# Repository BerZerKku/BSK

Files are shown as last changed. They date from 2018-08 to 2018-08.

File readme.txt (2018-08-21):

Плата BSK.
Сделана в OrCAD 16.6-2015-S073.

BSK_02v4

Код ПП: 3.140.786
Код ПП в сборе (1-16 команды): 2.141.036

Предназначена для работы в любом командном аппарате АВАНТ.

Изенения:

Ширина контактных площадки TQFP уменьшена на 0.05мм.
Добавлены супрессоры в цепях +24VE, +3.3V
Добавлены тестовые колодки и светодиоды

***Стэк:
35мкм  TOP
0.36мм e=4.5
35мкм  IN1_GND
0.71мм e=4.5
35мкм  IN2_PWR
0.36мм e=4.5
35мкм  BOTTOM

Материал: FR4 High Tg (e=4.1, plating thickness=25um))
Финишное покрытие контактных площадок: HAL
Паяльная маска: зеленая.
Вырезы на плате нет.
Отверстия указаны после металлизации.
***Технологическое поле не менее 5мм по всем сторонам, скрайбированием.

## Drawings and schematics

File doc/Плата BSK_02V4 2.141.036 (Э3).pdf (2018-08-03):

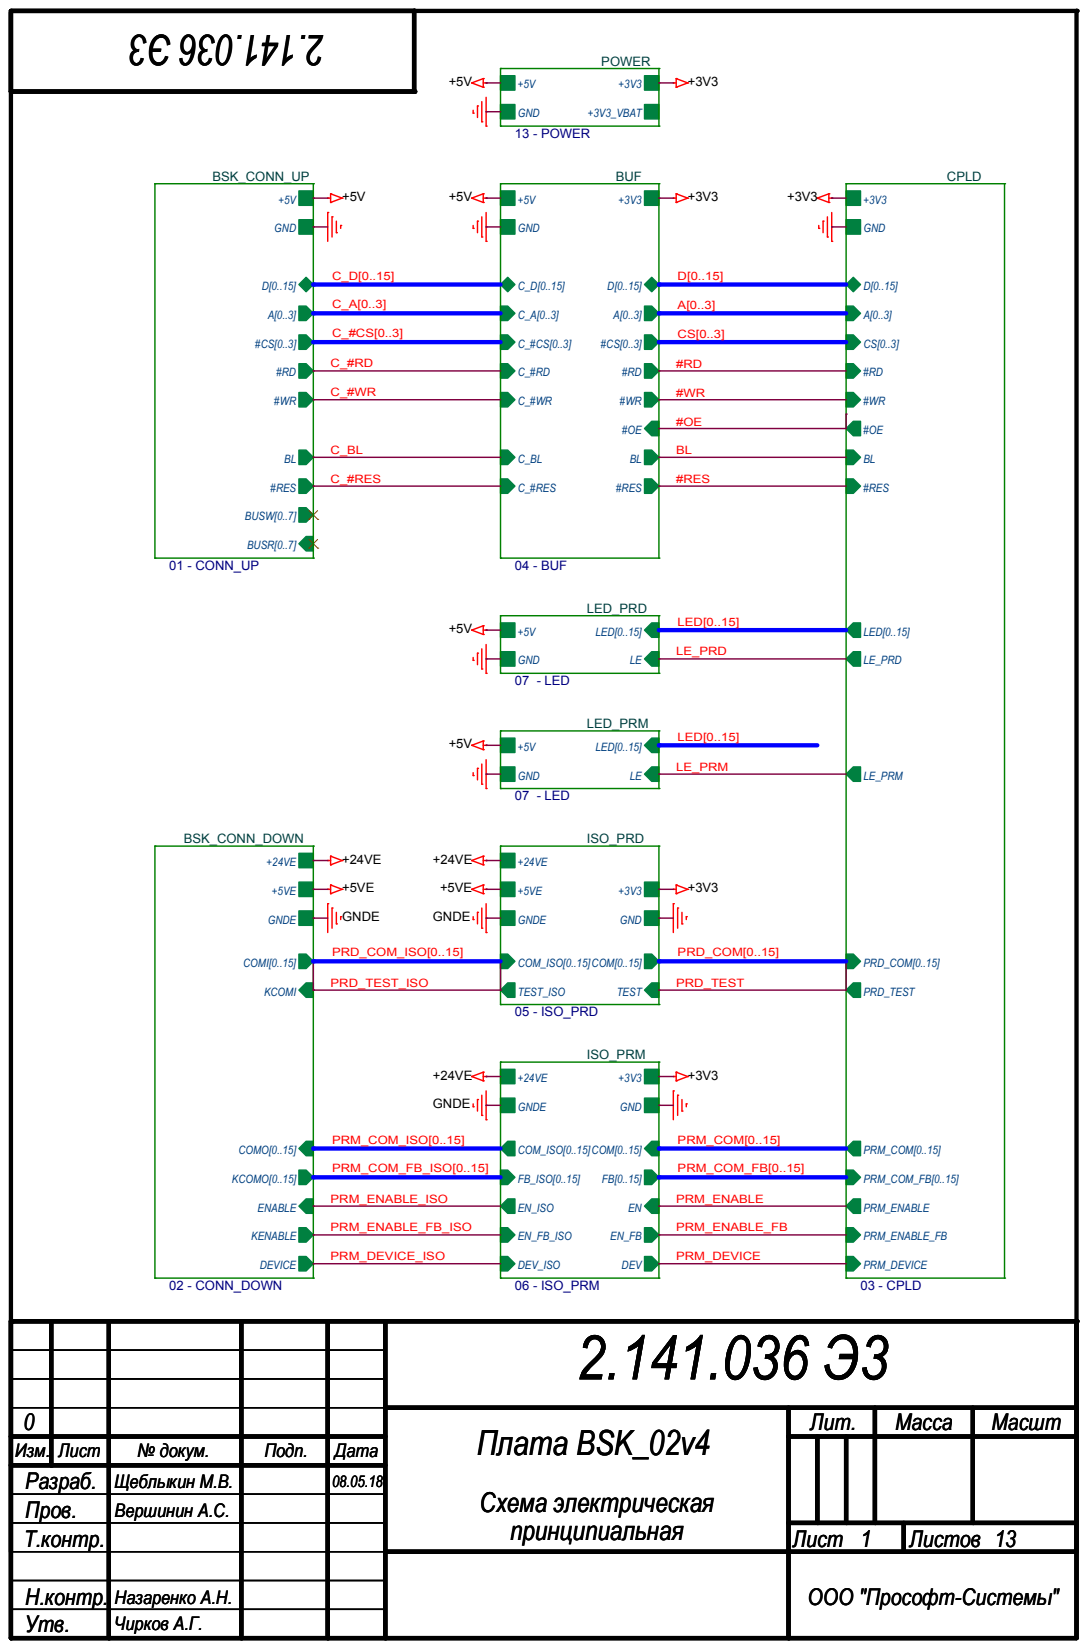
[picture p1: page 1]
GNDE; 0 Лит.; BUF; 04 - BUF; #RES; C_#RES; GND; LED_PRD; 07 - LED; LED[0..15]; ISO_PRM; 06 - ISO_PRM; FB_ISO[0..15]; EN_FB_ISO; DEV_ISO; DEV; EN_ISO; COM_ISO[0..15]COM[0..15]; CPLD; 03 - CPLD; PRD_COM[0..15]; PRM_COM[0..15]; LE_PRM; LE_PRD; PRM_ENABLE; PRD_TEST; PRM_COM_FB[0..15]; PRM_ENABLE_FB; PRM_DEVICE; POWER; 13 - POWER; +3V3_VBAT; LED_PRM; BSK_CONN_DOWN; 02 - CONN_DOWN; ENABLE; KENABLE; DEVICE; KCOMI; COMI[0..15]; COMO[0..15]; KCOMO[0..15]; BSK_CONN_UP; 01 - CONN_UP; BUSW[0..7]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

PRM_COM_FB_ISO[0..15] | PRM_COM_FB[0..15]

PRM_ENABLE_ISO | PRM_ENABLE

PRM_ENABLE_FB_ISO | PRM_ENABLE_FB

PRM_DEVICE_ISO | PRM_DEVICE

0 | | | | | Плата BSK_02v4 Плата BSK_02v4 Плата BSK_02v4 Схема электрическая Схема электрическая Схема электрическая | Лит. | Масса Масса Масса | Масшт Масшт Масшт
Изм. Изм. Изм. | Лист Лист Лист | № докум. № докум. № докум. | Подп. Подп. Подп. | Дата Дата Дата
Разраб. Разраб. Разраб. | | Щеблыкин М.В. Щеблыкин М.В. Щеблыкин М.В. | | 08.05.18 08.05.18 08.05.18
Пров. Пров. Пров. | | Вершинин А.С. Вершинин А.С. Вершинин А.С.
принципиальная Т.контр. принципиальная Т.контр. принципиальная Т.контр. | Лист Лист Лист 1 13 1 13 1 13 | Листов Листов Листов

Н.контр. Н.контр. Н.контр. | Назаренко А.Н. Назаренко А.Н. Назаренко А.Н.
Утв. Утв. Утв. | Чирков А.Г. Чирков А.Г. Чирков А.Г.

ООО "Прософт-Системы" ООО "Прософт-Системы" ООО "Прософт-Системы"

PROSOFT-SYSTEMS | TEXT

## MARKING STICKER

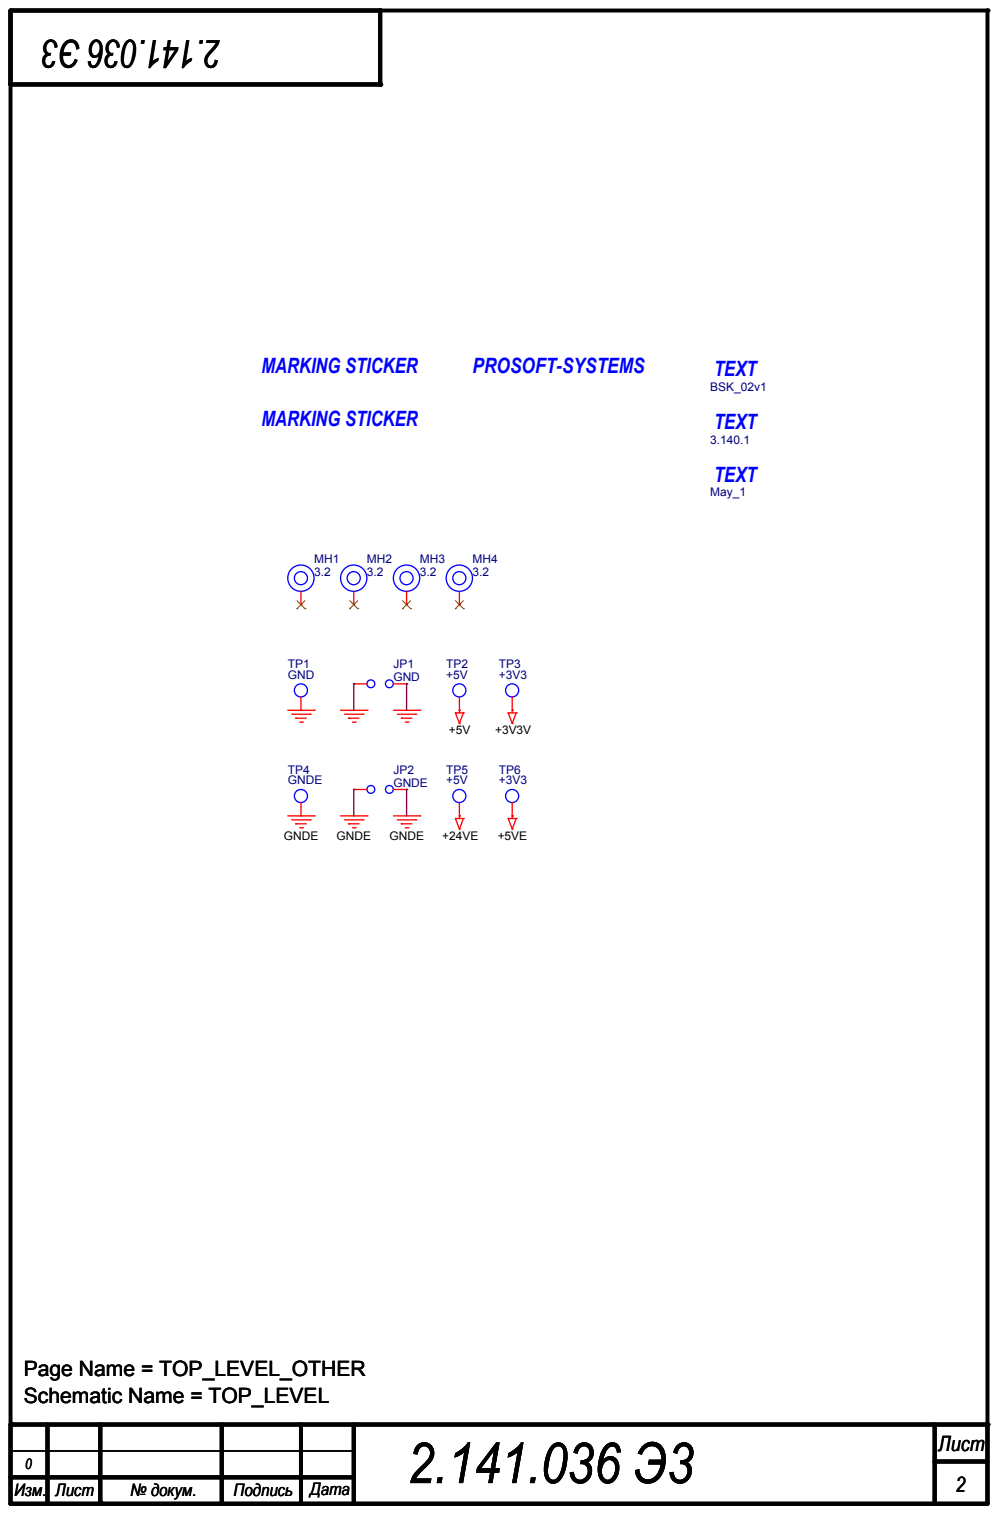
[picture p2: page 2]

Лист 2.141.036 Э3 Лист 2.141.036 Э3 Лист 2.141.036 Э3 2 2 2

Изм. | Лист | № докум. | Подпись | Дата

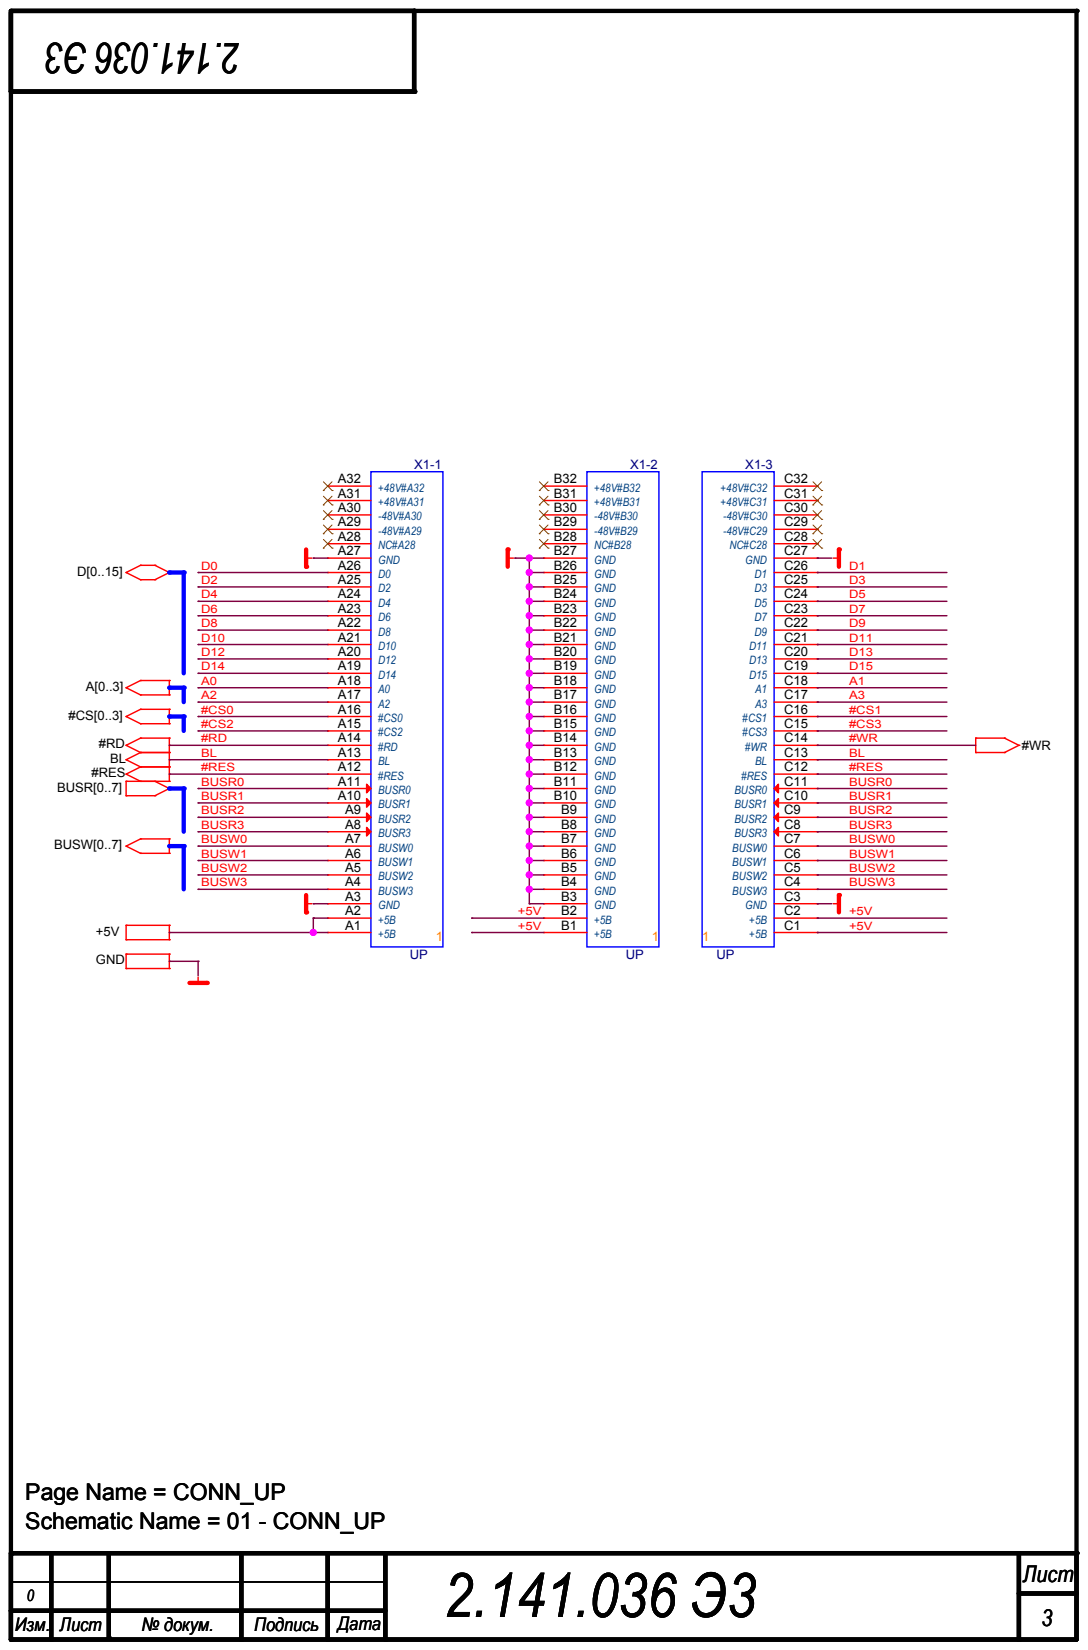
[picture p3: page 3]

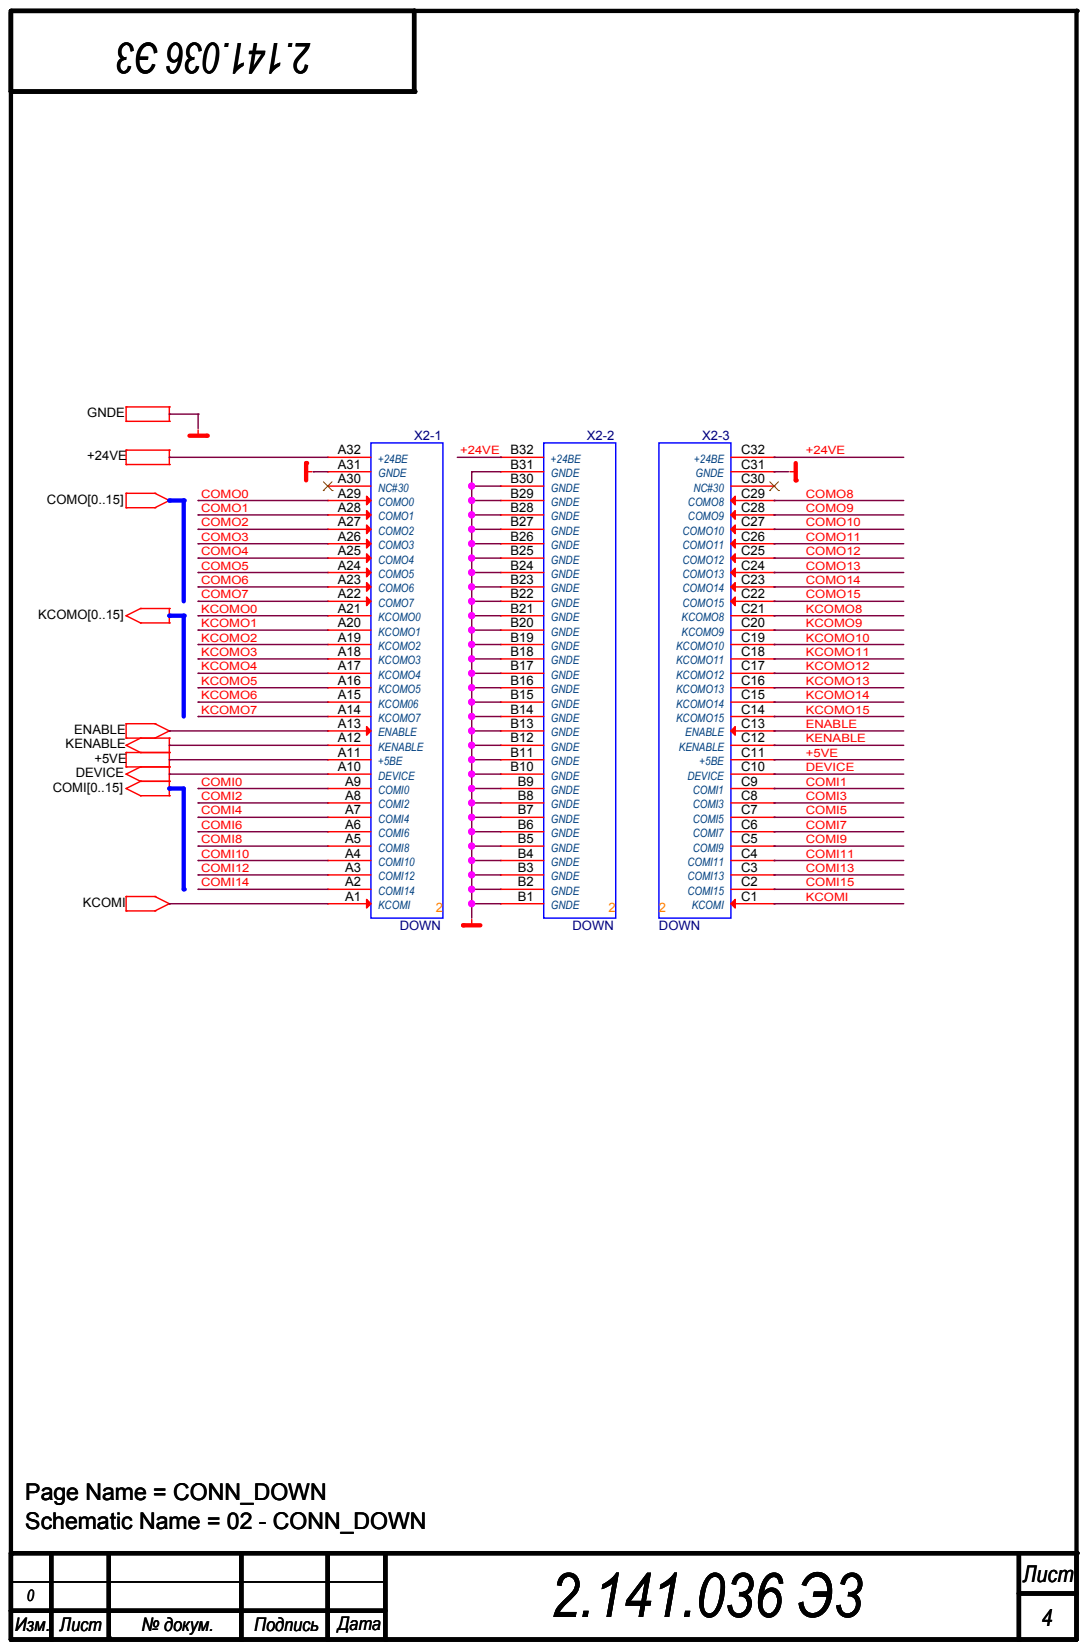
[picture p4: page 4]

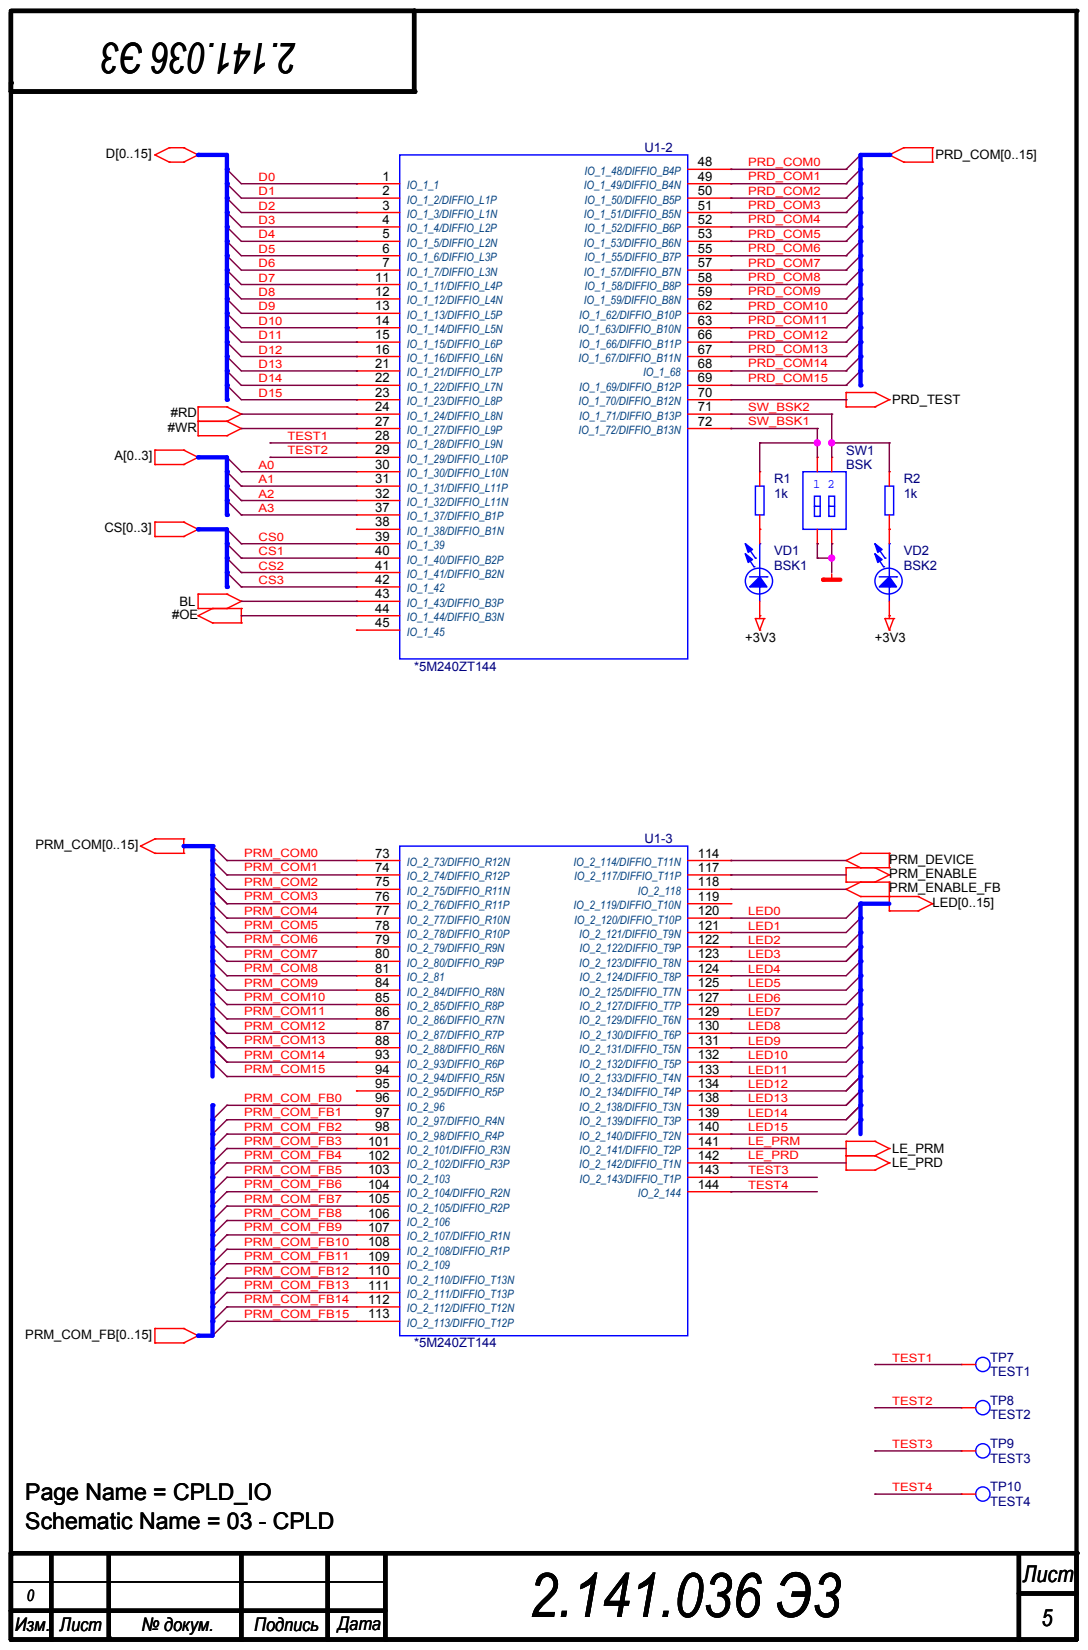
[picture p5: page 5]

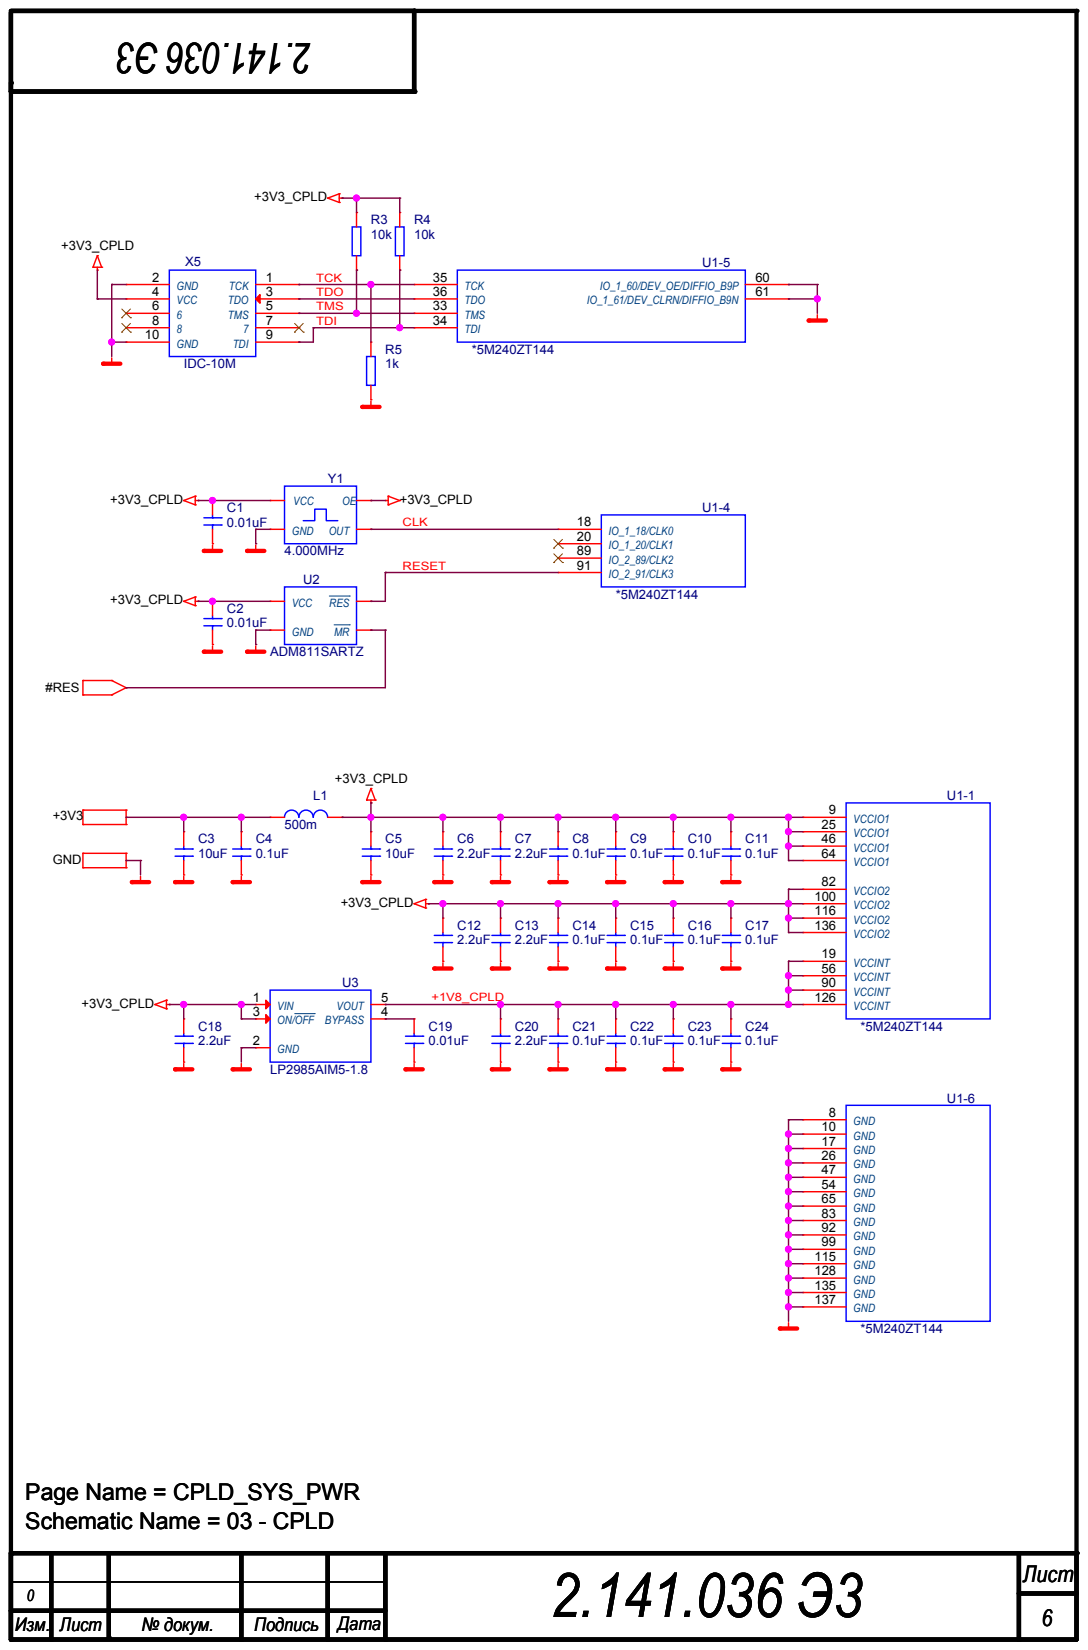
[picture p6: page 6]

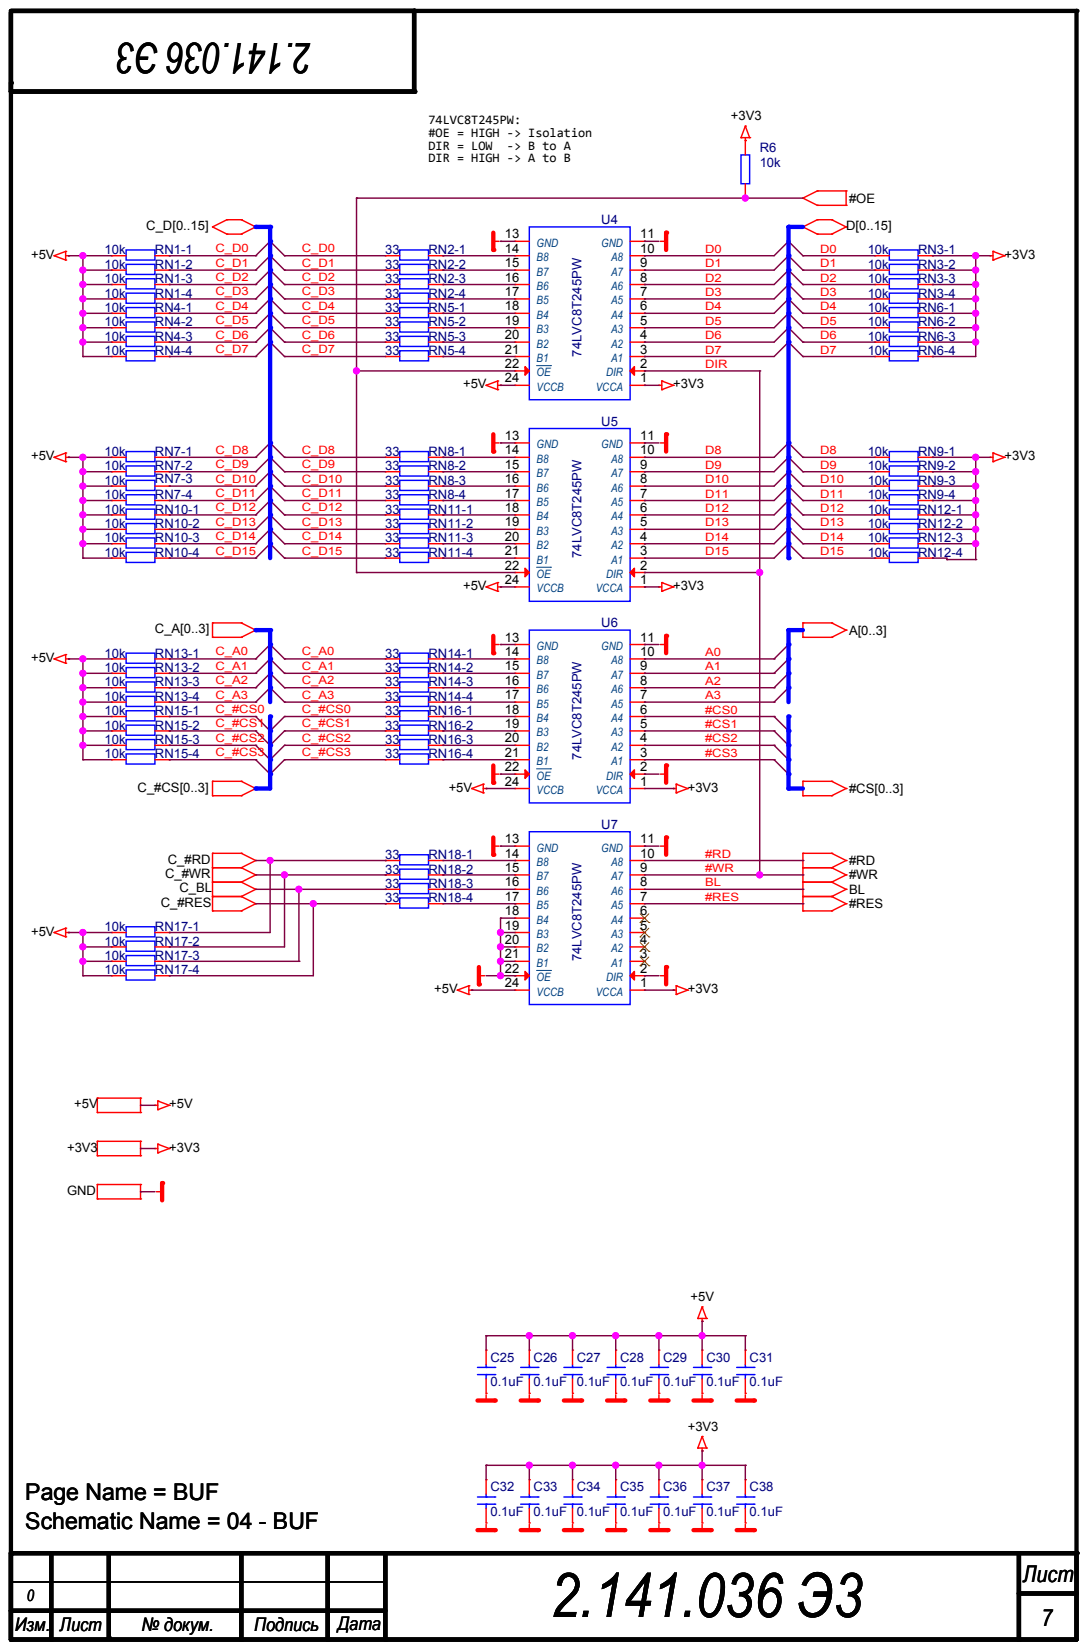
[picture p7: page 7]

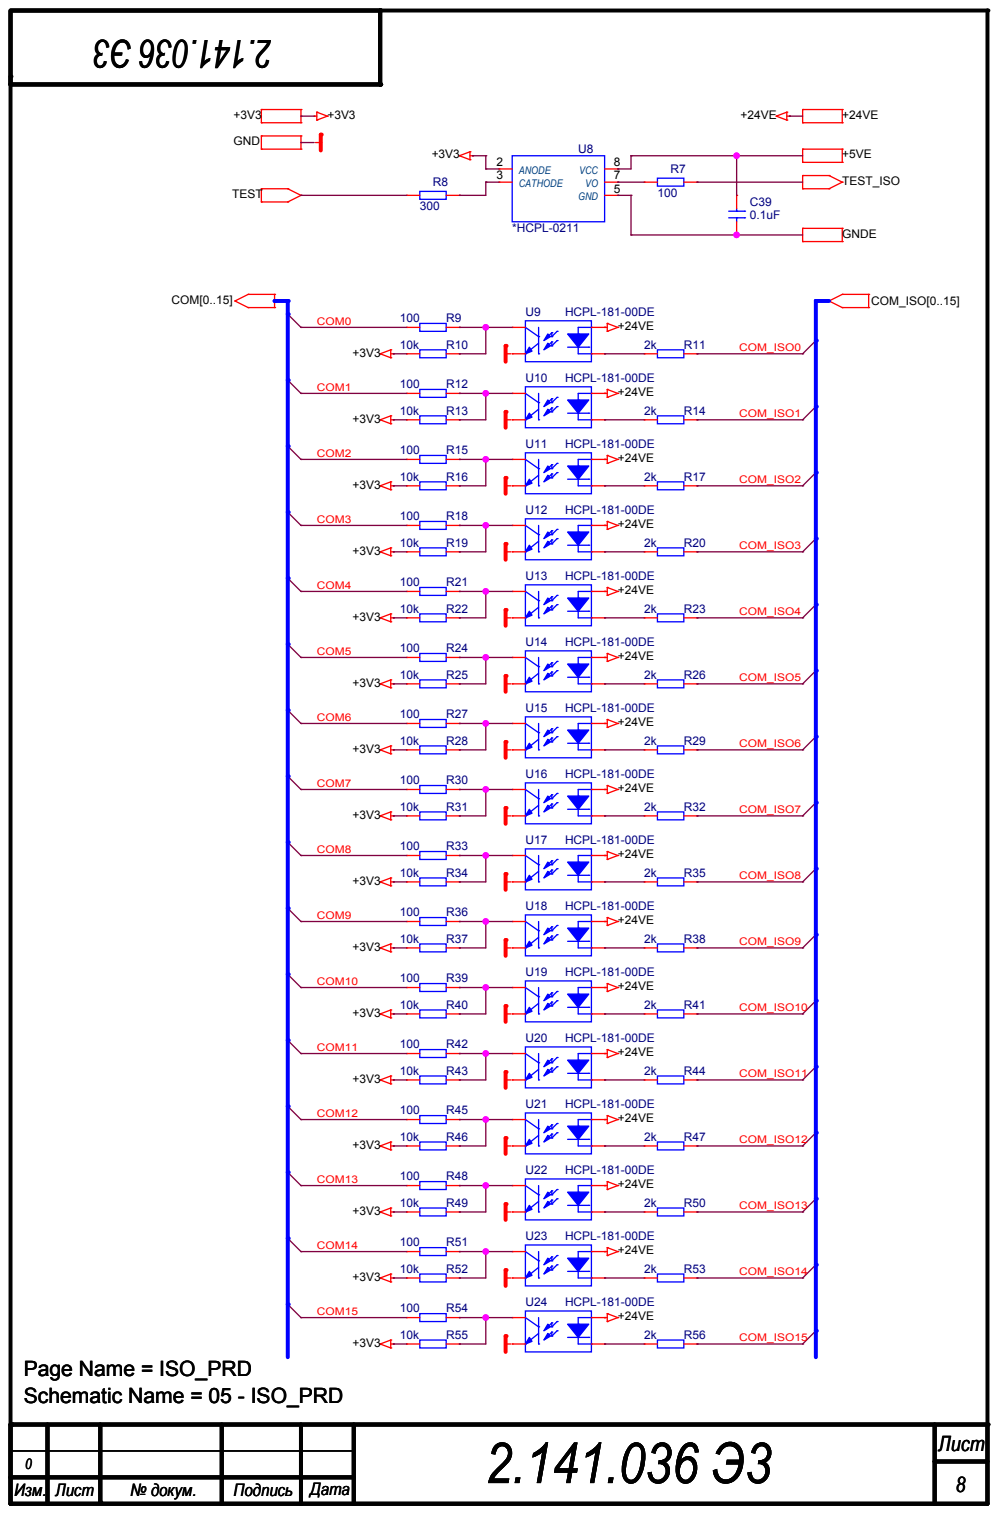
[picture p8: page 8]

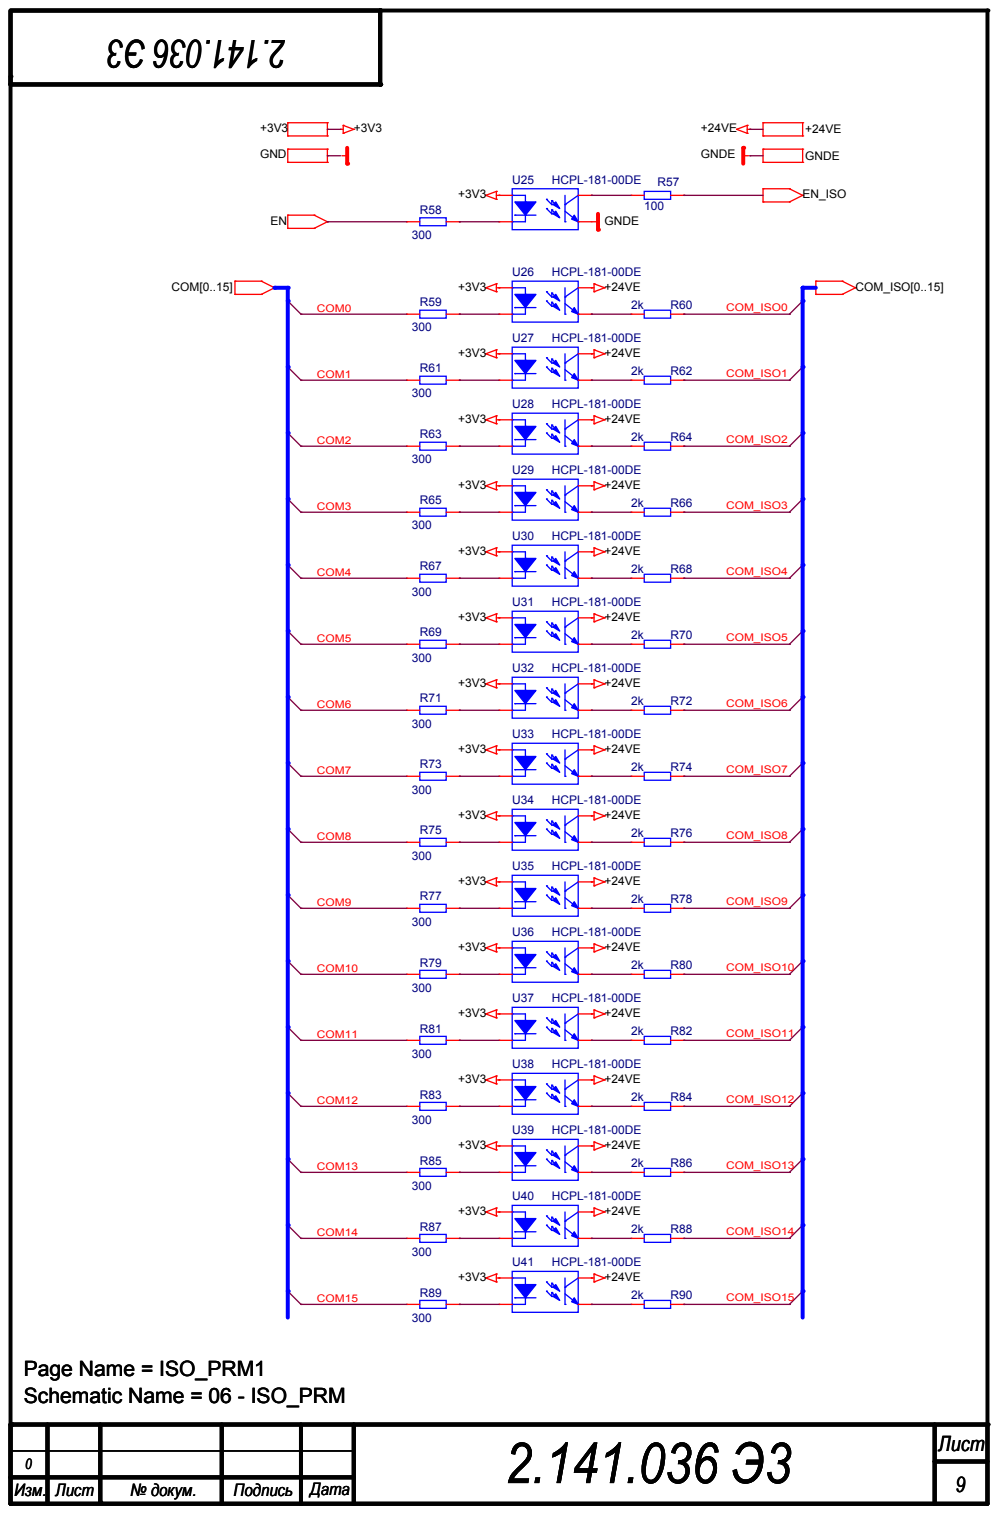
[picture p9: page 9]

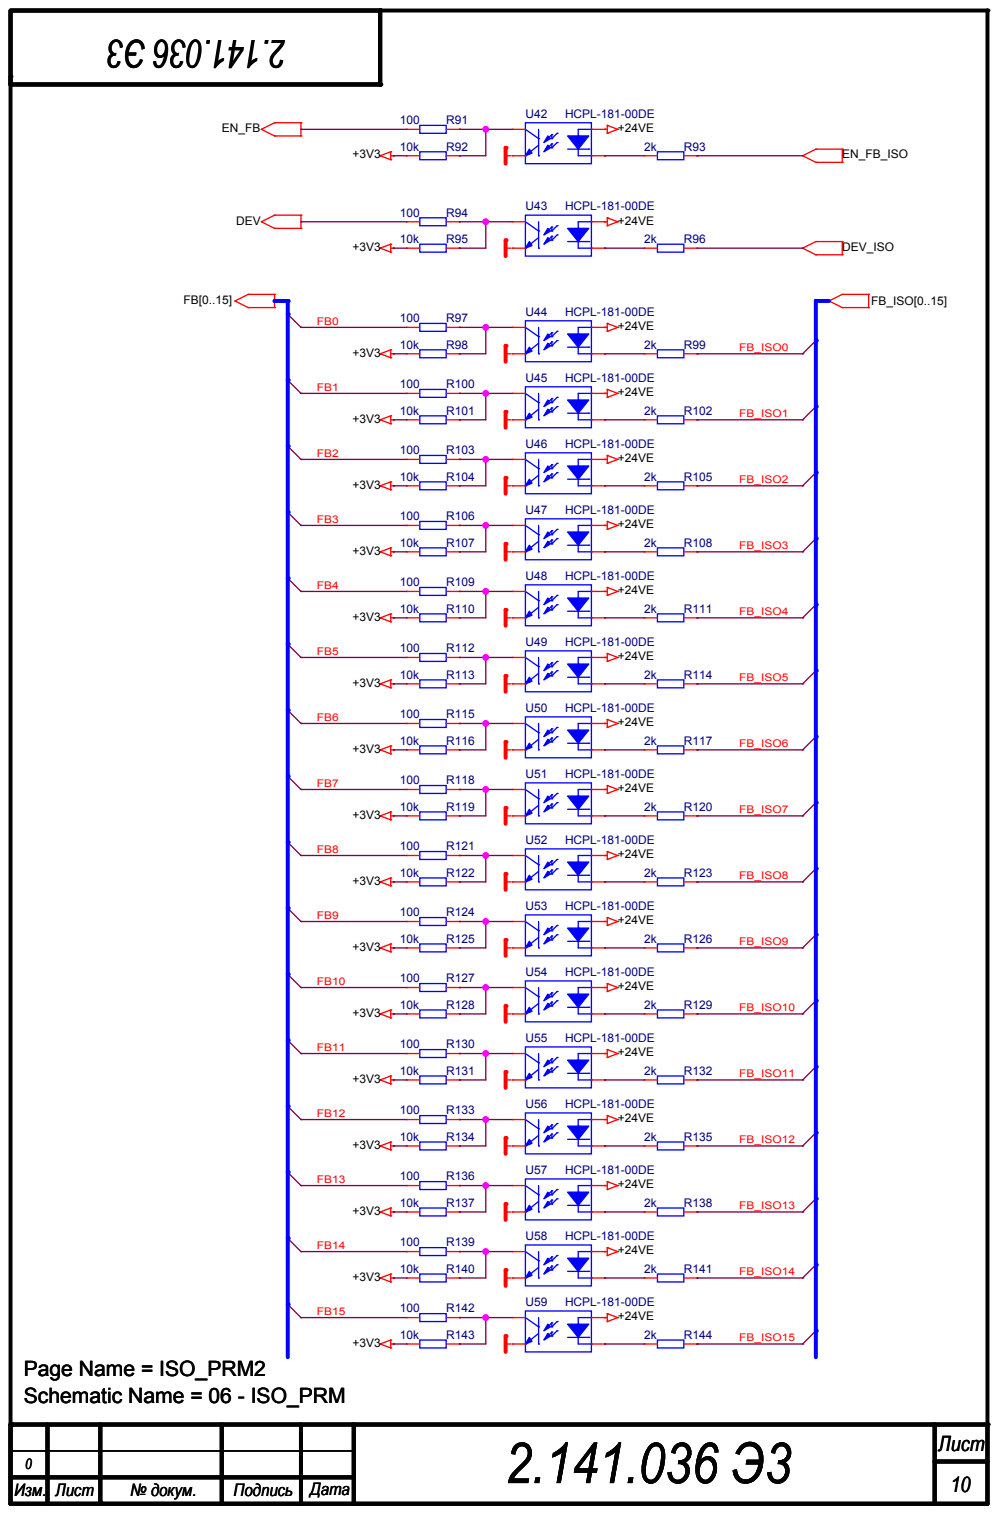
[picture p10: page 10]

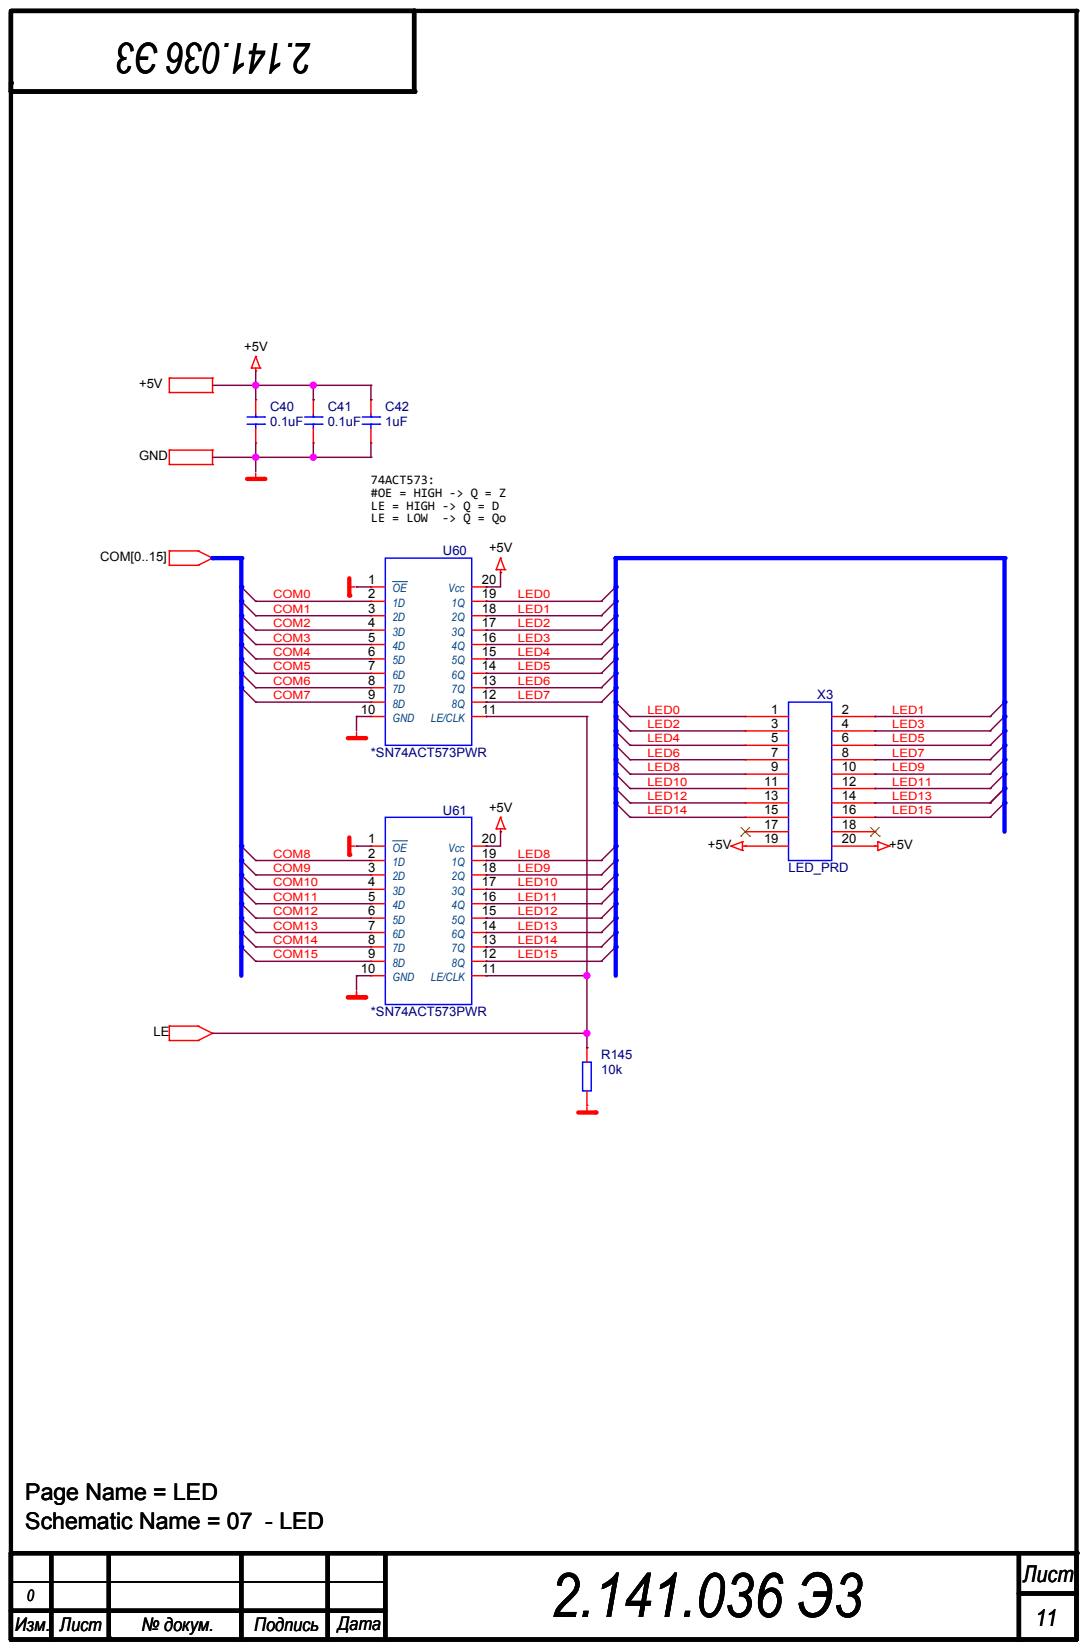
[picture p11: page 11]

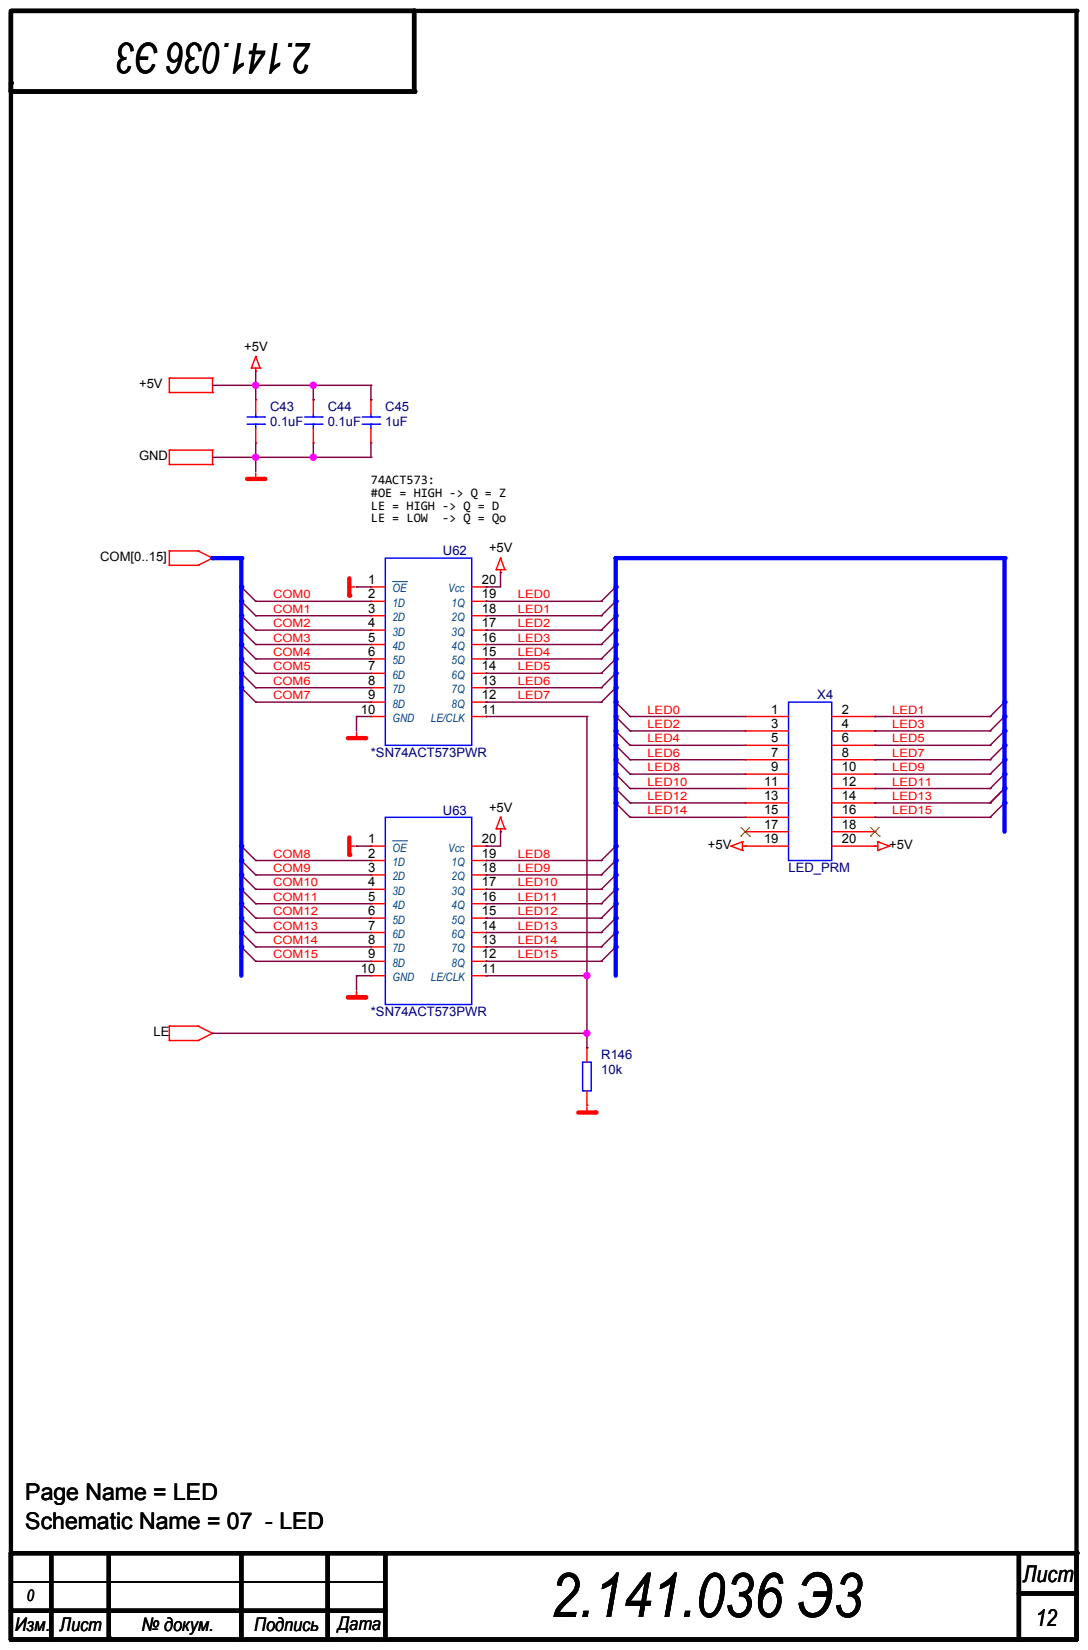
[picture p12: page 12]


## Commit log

2014-01-27 Первый комит за много лет.
    текущая плата БСК 023, сборка ревизия 1, спецификация - 7
    [BSK_023.sch, Плата БСК-023 (СБ).dwg]
2014-04-08 Изменена структура файлов. Из пути убрана папка BSK_023.
    [BSK_023.sch, Плата БСК-023 (СБ).dwg]
2014-04-08 Добавлена документация по доработке платы BSK_023 запаянной по основному варианту на 4 команды, до платы на 8 команд.
    [Плата БСК BSK_023 (СБ).dwg, Плата БСК BSK_023 доработка 4 в 8 (СБ).dwg]
2014-04-08 Текущая документация на плату объединена в один файл.
2014-04-09 На листе ревизий исправлен Титул.
2016-12-28 СП rev.9 Добавлен аналог для DIN 96/
2017-06-28 СП rev.10 С54 убран из поз. 7.
2017-08-09 Обновлен файл СБ + СП. В предыдущем осталась старая версия.
2018-08-03 Начата работа над переделкой платы.
    [BSK_023.sch, BSK_02v4.DSN, Плата БСК BSK_023 (СБ).dwg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]
2018-08-06 Переназначены и разведены выводы ПЛИС
    [BSK_02v4.DSN]
2018-08-10 Разведена плата, нет шелкографии, не проверены ошибки, не обновлены выводы ПЛИС.
2018-08-14 Устранены замечания. Плата готова к обновлению пинов ПЛИС на схеме.
2018-08-15 Обновлены выводы ПЛИС Добавлены тестовые индикаторы и тестовая колодка Улучшен теплоотвод преобразователя Устранены слипания вырезов вокруг переходных отверстий
    [BSK_02v4.DSN]
2018-08-21 Устранены замечания Добавлены конденсаторы ТОР-ВОТ в цепях 3.3В, 5В, 24В Добавлены супрессоры в цепях 3.3В, 24В Нанесена шелкография Обновлена схема
    [BSK_02v4.DSN]
2018-08-31 Добавлены обозначения на шелкографии.
2018-09-10 отодвинул дорожки от края платы, идущие к буферу светодиодов индикации команд. лучше бы не подводить дорожки близк к краю полигона - там помехи. а дорожки идут в ПЛИСку.
